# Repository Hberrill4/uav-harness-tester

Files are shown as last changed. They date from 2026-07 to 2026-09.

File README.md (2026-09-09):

# UAV harness continuity tester

ESP32-based automated continuity tester for a 64-wire UAV wiring harness.
Detects open circuits, shorts, and wire mismatches, and reports the exact
wire location of each fault. 

A custom PCB: [PCB](Workflow/Project-files/WireHarnessTesterPCB.zip) , [PCB schematic](Workflow/Project-files/WireHarnessTesterSchematic.zip) , 

and custom Enclosures:
[Main tray](Workflow/Project-files/Final_Tray.stl) ,
[Main lid](Workflow/Project-files/Final_Lid.stl) , 
[Test pod tray](Workflow/Project-files/Box%20for%20test%20pod%20v2.stl) , 
[Test pod lid](Workflow/Project-files/lid%20new.stl)

was designed made for this project

## How it works

One button drives everything:

- **Short press** — runs a test (normal mode) or captures a golden
  reference sample (admin mode)
- **Hold 5 seconds** — toggles between normal and admin mode (LCD turns
  blue in admin mode)

Every test scans all 64 wires against all 64 sense channels (not just a
1:1 diagonal check), which is what makes shorts and mismatches detectable,
not just opens. Results show on the LCD (pass = green, fail = red,
admin = blue) and get logged with a timestamp to the SD card.

See [Workflow/fault-report-format.md](Workflow/fault-report-format.md) for what a
fault report looks like and how faults are classified.

See [Workflow/User Manual](Workflow/User%20Manual) for full manual

## Table of contents

### src/
- **[Config](src/Config.h)** — All pin assignments, timing constants, wire count. File to edit hardware changes.
- **[main.cpp](src/main.cpp)** — Owns the state machine (normal/admin, test/capture)
- **[ButtonManager.](src/ButtonManager.h)** — Non-blocking debounce + short-press vs 5s-hold detection
- **[MuxController](src/MuxController.h)** — Addresses any of the 64 wires across the drive/sense mux banks
- **[ContinuityTester](src/ContinuityTester.h)** — Runs the full 64×64 connectivity scan
- **[FaultAnalyzer](src/FaultAnalyzer.h)** — Classifies faults: OPEN / SHORT / MISMATCH, with location
- **[WireMap](src/WireMap.h)** — Converts wire index → connector+pin label (e.g. "J1-13")
- **[DisplayManager](src/DisplayManager.h)** — LCD + RGB
- **[StorageManager](src/StorageManager.h)** — SD card logging + golden sample persistence

### Workflow/
- **[wiring-reference.md](Workflow/wiring-reference.md)** — Hardware assumptions baked into the code, pin mapping conventions
- **[fault-report-format.md](Workflow/fault-report-format.md)** — What fault reports look like and how they're generated
- **[Assembly](Workflow/Assembly/)** — The process behind the prototype and how everything was made
- **[Design-Architecture](Workflow/Design-Architecture/)** — General system layout and how components interact and connect
- **[Design-Enclosure](Workflow/Design-Enclosure/)** — Modular test pod and enclosure for bench-top testing
- **[Design-PCB](Workflow/Design-PCB/)** — PCB design process and final product
- **[Hardware](Workflow/Hardware/)** — Components considered and finalized design decisions
- **[Images](Workflow/Images/)** — Contains all images used throughout the documentation
- **[Project-files](Workflow/Project-files/)** — Contains all external project files
- **[User Manual](Workflow/User%20Manual/)** — Full user manual covering operation, maintenance, and troubleshooting
    
**platformio.ini**            Build config (ESP32, Arduino framework)

## Project Files

- [Bill of Materials](/Workflow/Project-files/BOM%20for%20project.csv)
- [Gant Chart](/Workflow/Project-files/Gant%20Chart.xlsx)
- [Test pod BOM](/Workflow/Project-files/Test%20pod%20BOM.pptx)
- [Adaptor BOM](/Workflow/Project-files/Adaptor%20BOM.pptx)

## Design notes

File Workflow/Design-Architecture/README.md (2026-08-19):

# Design Architecture

## Requirements

- Minimum 50 wires
- Stand-alone device
- Modular test pods (adaptor for multiple wire connectors)
- Display screen (shows pass/fail and fail type)
- Memory storage for matrices and results (golden sample)
- Display location and type of fail
- Sturdy, universal wire connection resistant to in/out movement, easy to click in

## Design Evolution

**Initial idea:** Store multiple harness types on an SD card, load the relevant one into RAM, and compare it against the connected harness, navigated via a scroll-wheel menu (new harness / test / view results). Rejected — only one "golden sample" is needed at a time, and this added test time and complexity without being user friendly. It would also create admin problems and using the scroll wheel may cause issues.

**Input method thinking:** The goal was a single button for most users, with a touch-screen password for admins to change the golden sample. Since a separate touch-input screen would undermine the simplicity goal, the team settled on using the same button for everything. This touch screen would then be two seperate screen which woukd overcomplicate the process and cause the test box to be too bulky.

## Final Design

A single button provides all input.

- **Normal use:** connect harness → press button → test runs → result + timestamp logged to SD → result shown on screen.
- **Admin mode:** hold the button 5 seconds to enter admin mode (shown via icon/text color change); connecting the golden sample and pressing the button stores it as the new reference. Hold 5 seconds again to exit.
- **Status colors:** Pass = green, Fail = red, Admin = blue.

This keeps the interface simple for everyday users while keeping the golden-sample update path deliberately non-obvious, and all results (with timestamps) are recoverable by plugging the SD card into a PC.
## Harness/cable considerations
A DSub mount connected to a ribbon cable which can connect to the Dsub connector on the outside of the box would keep everything contained and have a fixed position to conect to on the outisde of the box. Using Dsub wire connectors for our floating umbilical cords should also keep the connection stable and be resistant to general use. DIN connectors were also considered but problems with sturdiness and reliability of connection arose aswell as number of pins as the tester is designed to accomadate for a 64 wire loom.

## Component Architecture
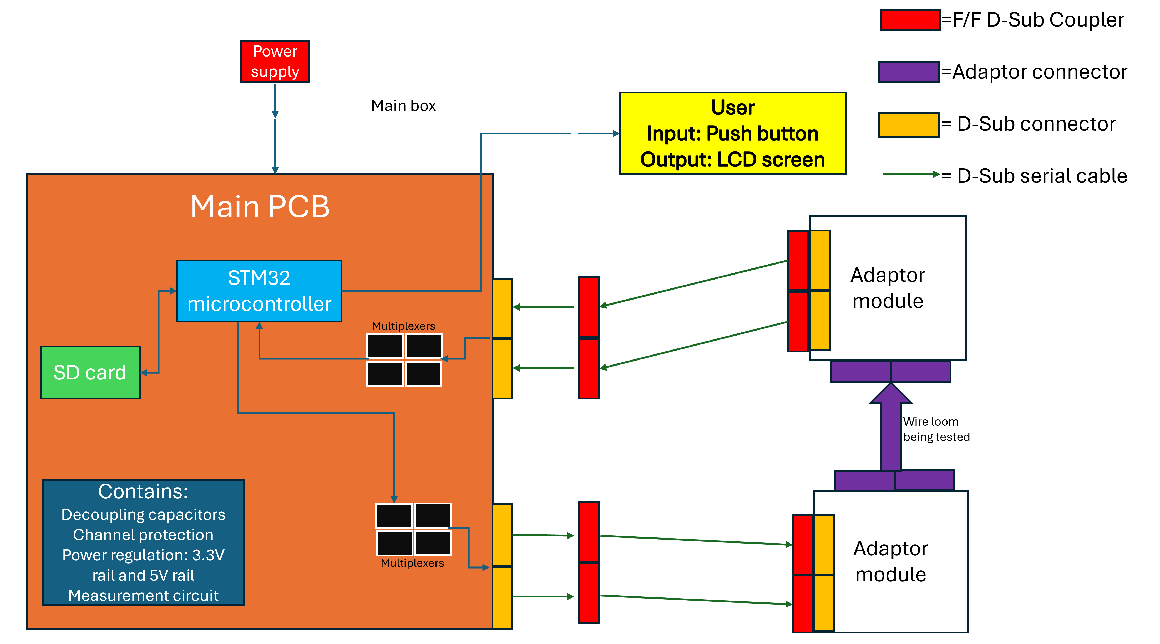
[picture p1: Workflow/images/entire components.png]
Component architecture diagram

The main box houses the Main PCB (ESP32-S3 microcontroller, multiplexers, SD card, decoupling capacitors, channel protection, and power regulation providing a 3.3V rail) plus the push-button input and LCD output. Two adaptor modules connect through D-Sub couplers and cabling to the wire loom under test.

## Operating Process
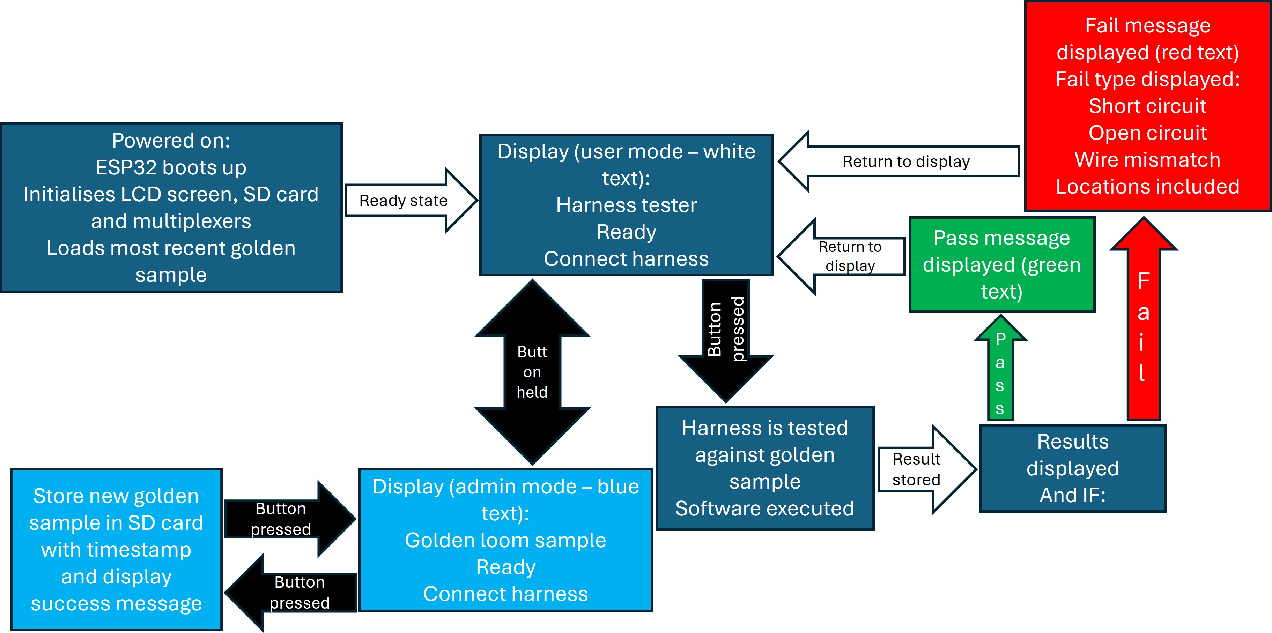
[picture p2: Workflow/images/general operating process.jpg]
General operating process diagram

On power-up, the ESP32 boots, initializes the LCD, SD card, and multiplexers, then loads the most recent golden sample. In user mode the display reads "Harness tester — Ready — Connect harness." Pressing the button runs the test against the golden sample; a pass shows a green message, a fail shows red with the fail type (short circuit, open circuit, or wire mismatch) and location. Holding the button switches to admin mode (blue text, "Golden loom sample — Ready — Connect harness"), where pressing the button stores a new golden sample to the SD card with a timestamp.

## Block Diagram
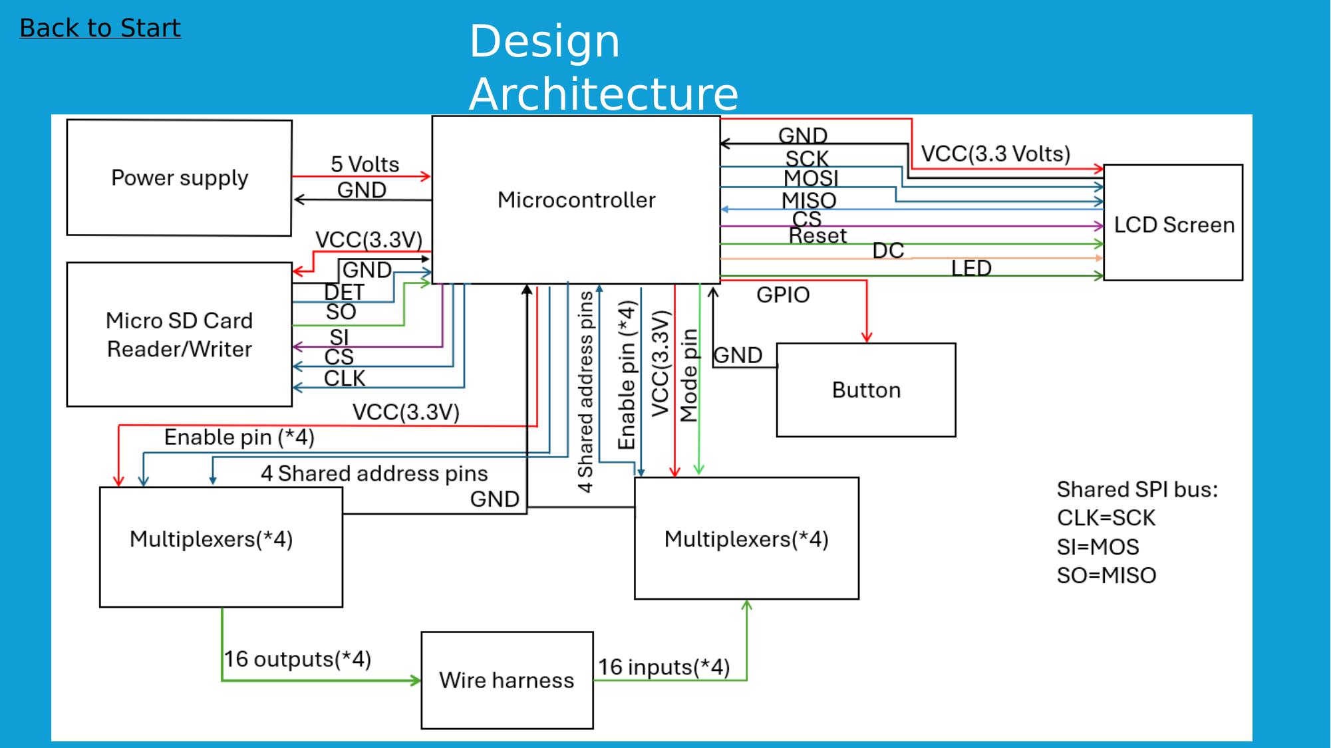
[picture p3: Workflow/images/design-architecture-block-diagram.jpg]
Block diagram

Shows the electrical connections between the power supply, microcontroller, LCD screen, microSD card reader/writer, button, and two sets of multiplexers, including the shared SPI bus (CLK/SI/SO mapped to SCK/MOSI/MISO) and the 16-input/16-output connections to the wire harness under test.

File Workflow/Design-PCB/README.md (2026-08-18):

# PCB Design

This document covers the custom PCB design using the software KiCAD for the UAV wire harness continuity tester: an ESP32-S3-based instrument that tests all 64 wires of a UAV harness for continuity and fault conditions, logs results with timestamps, and displays outcomes on an onboard TFT via a single-button interface.

See the [main README](../../README.md) for the full project overview and [`Workflow/Hardware`](../Hardware/) for the core hardware review that shaped these decisions and [Test pod Bill of Materials](https://github.com/Hberrill4/uav-harness-tester/blob/main/Workflow/Project-files/Test%20pod%20BOM.pptx) for the full list of test pod hardware used and [Adaptor pod Bill of Materials](https://github.com/Hberrill4/uav-harness-tester/blob/main/Workflow/Project-files/Adaptor%20BOM.pptx) for full list of adaptor hardware. Each PCB contains components of their respective BOM.

Final Test Pod Schematic: [Active PCB Schematic](https://github.com/Hberrill4/uav-harness-tester/blob/main/Workflow/Project-files/Active%20PCB%20Schematic.zip)

Final Test Pod PCB:

---

## Architecture at a glance

- ESP32-S3 drives 8× CD74HC4067 16-channel multiplexers (4 "drive" / 4
  "sense") to scan a full 64×64 wire matrix
- Results are logged to microSD and shown on a 2.8" TFT
- A single push button handles all user input, including an
  administrator mode
- The harness under test connects via modular pods over a floating
  umbilical interconnect

## Functional requirements

**Test coverage**
- Test all harness wires (up to 64) for continuity and fault conditions
- Store a golden sample reference in RAM and persist it to SD card

**Data & UI**
- Log every test result with a timestamp
- Display results on the 2.8" TFT
- Operate entirely from a single push button, including an administrator mode

**Interconnect**
- Interface with modular test pods over a floating umbilical
- Internal PCB-to-connector runs use IDC ribbon cable; the external
  umbilical uses a high-density D-sub or keyed circular connector with
  28–30 AWG stranded conductors, chosen for flex durability over repeated
  connect/disconnect cycles

**Electrical**
- USB-C input, 3.3V logic, SPI for TFT/SD, multiplexer channel switching
- Protection on all ESP32-facing measurement inputs

**A breadboard prototype was built and validated first** — see
[`../Assembly/`](../Assembly/) for the bring-up log — before committing
to PCB layout.

## Schematics
KiCAD was used to route all traces. Although a decision was made to mount the hardware components ourselves it was key to ensure the right components were selected in KiCAD to maintain the same dimensions and pin outs. Additional software like espressif was downloaded to ensure such accuracy could be maintained.

## Circuit protection

#### TVS Diode (4 Channel) — ESDR0524SMUTAG
The primary ESD/transient protection device on the board. Each package contains 4 low-capacitance channels, clamping voltage spikes on signal lines to a safe level whenever the external wiring harness is connected or disconnected — the most likely source of electrostatic discharge into the sense/mux lines. The low-capacitance rating matters here because it protects the matrix scan lines without materially loading them or slowing signal edges.

#### 10 µF Electrolytic Capacitor — MCESL16V106M4X5.2
Bulk reservoir capacitance. It provides a low-impedance path to absorb and dump the energy from any transient a TVS diode clamps, and smooths lower-frequency ripple on the rail — complementing the fast, small-value ceramics rather than replacing them. The 16V rating gives comfortable headroom above the logic/supply rail it's protecting.

#### 10 kΩ Resistor — RT0805FRE0710KL
Used as a pull-up resistor on the protected lines holding them at logic level 1 when nothing is actively driving them (e.g. before a harness is connected). This prevents floating inputs from producing false continuity/fault readings, working alongside the TVS clamping.

#### 0.1 µF Decoupling Capacitor — GCM155R71H104KE02J
Local high-frequency decoupling, placed as close as possible to IC power pins. It filters fast switching noise and supplies instantaneous current during transients, keeping the supply rail stable — standard practice paired with the bulk electrolytic above.

## Design workflow

-  Draft schematic — measurement circuit, power flags, net labels, test points, decoupling
-  Run ERC and resolve until clean
-  Assign footprints and verify against datasheets
-  Get schematic reviewed and approved
-  Import schematic into PCB editor
-  Arrange components — wide power traces, digital/analog separation
-  Route traces
-  Add ground plane
-  Run DRC
-  Inspect in 3D
-  Final review against schematic

**A breadboard prototype was built and validated first** — see
[`../Assembly/`](../Assembly/) for the bring-up log — before committing
to PCB layout.

## Known issues carried from design review

- Two GPIO pin conflicts (SD chip-select vs. mux enable; SPI clock/data
  vs. the Octal PSRAM bus) were identified and resolved during firmware
  bring-up — see commit history in `firmware/Config.h`
- Protection/measurement circuit block was absent from the original
  schematic and is being added in this revision
- Mux bank labeling was ambiguous when both banks looked identical on the
  original diagram; corrected with distinct drive/sense labeling

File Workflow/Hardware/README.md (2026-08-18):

## Microcontrollers Considered

**ESP32** — 45 changeable GPIO, 4 SPI, 3 UART, 2 I2C, 240 MHz clock, 8 MB flash, 512 KB SRAM, 384 KB ROM, 3.3 V logic. ([ESP32-S3-DEV-KIT-N8R8 overview](https://www.waveshare.com))

**Arduino Mega** — 16 analog inputs, 54 digital I/O (15 PWM), 4 serial ports, 16 MHz clock, 256 KB flash (8 KB used by bootloader), 8 KB SRAM, 4 KB EEPROM, 3.3 V logic.

The ESP32 is faster with more RAM/flash (good for future/industrial expansion) but its 3.3 V logic complicates inclusion. The Arduino Mega tests matrices one at a time — slightly slower, but makes good use of the SD card.

Finally the ESP32 was preferred as it provided more internal RAM which would allow the 64x64 matrices to be accessed in this way and improve the speed of the system massively as well as ease of use.

## Research: Existing Testers

| Tester | Source | Notes |
|---|---|---|
| Tester 1 | [theseus.fi thesis](https://www.theseus.fi/bitstream/handle/10024/801631/Ech-charef_Rania.pdf) | Discusses how to measure resistance during the process |
| Tester 2 | [hackaday.io – ArduWire Uno](https://hackaday.io/project/176753-arduwire-uno-low-voltage-cable-tester) | Uses a MUX/DEMUX 4067 IC to select pins, plus LEDs for a visual pass/fail indication; schematics provided, built around an Arduino Uno |
| Tester 3 | [Griffith University repository](https://research-repository.griffith.edu.au/server/api/core/bitstreams/e0df58bc-e96a-434f-b30a-f2ac24138317/content) | Covers wire harness testing methodology with a flow chart of the testing process |

## Other Component Considerations
- Was tough to find connecting cables that accommodated for a 64 wire harness so a decision was made to split it in half and use 2 idc rainbow ribbon cables inside of the modular test pod as they are already protected in that way and to use 2 DSsub connectors as the floating umbilical cords as these can withstand the daily usage and strain.  
- I also looked at the screen and lcd screen being able to share SPI bus ports as this would then require less GPIO pins on the Arduino.  
- Another consideration was monitoring the noise and surges that would happen due to there being many MUX switches so ceramic capacitors would be needed to mitigate this.  
- The MUX would have to have 4 control pins and 16 input/output pins while being able to operate on the esp32 to allow for switching between 64 wires.  
- A rotary encoder was originally looked at to be able to scroll through options but a single push button was decided upon as this would be far more user friendly and be able to easily be mounted on the modular test pod and only require one user input.  
- Headers would also be required to connect to the DSub cables off the PCB.

## Final Core Hardware

**Microcontroller:** ESP32-S3-DEV-KIT-NXRX - 45 changeable GPIO, 4 SPI, 3 UART, 2 I2C, 240 MHz clock, 8 MB flash, 512 KB SRAM, 384 KB ROM, 3.3 V logic.

**Display:** 2.8" ILI9341 SPI TFT — 169 KB internal display RAM, 3.3 V logic, 6 GPIO pins.

**Storage:** MicroSD SPI/SDIO breakout board — shares the SPI bus, needing only one extra pin.

**Multiplexer/Demultiplexer:** CD74HC4067 — 2–6 V operation, 16 channels, 4 control pins, enable pin

**DSub connector:** 37 Pin Dsub to Dsub males

**Test pod connectors:** High Speed Data Transfer Cord DB37 Data Cable Wire D-Sub 37Pin

**Total Bom for test pod is provided below:**  
[Bill of Materials](https://github.com/Hberrill4/uav-harness-tester/blob/main/Workflow/Project-files/Test%20pod%20BOM.pptx)

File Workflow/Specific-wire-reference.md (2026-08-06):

| Connection Type | Colour | Wire Reference |
|---|---|---|
| 🔌**S1** |  |  |
| <small>PPM</small> | <small>White</small> | **J1-1** |
| <small>N/A</small> | <small></small> |  |
| <small>GND</small> | <small>Black</small> | **J1-2** |
| 🔌**S2** |  |  |
| <small>PPM</small> | <small>White</small> | **J1-3** |
| <small>N/A</small> | <small>N/A</small> |  |
| <small>N/A</small> | <small>N/A</small> |  |
| 🔌**S3** |  |  |
| <small>PPM</small> | <small>White</small> | **J1-4** |
| <small>VCC</small> | <small>Red</small> | **J1-5** |
| <small>GND</small> | <small>Black</small> | **J1-6** |
| 🔌**S4** |  |  |
| <small>PPM</small> | <small>White</small> | **J1-7** |
| <small>VCC</small> | <small>Red</small> | **J1-8** |
| <small>GND</small> | <small>Black</small> | **J1-9** |
| 🔌**S5** |  |  |
| <small>PPM</small> | <small>White</small> | **J1-10** |
| <small>VCC</small> | <small>Red</small> | **J1-11** |
| <small>GND</small> | <small>Black</small> | **J1-12** |
| 🔌**S6** |  |  |
| <small>PPM</small> | <small>White</small> | **J1-13** |
| <small>VCC</small> | <small>Red</small> | **J1-14** |
| <small>GND</small> | <small>Black</small> | **J1-15** |
| 📡**Receiver** |  |  |
| <small>4V5</small> | <small>Red</small> | **J1-16** |
| <small>T4</small> | <small>White</small> | **J1-17** |
| <small>R4</small> | <small>Yellow</small> | **J1-18** |
| <small>T2</small> | <small>Blue</small> | **J1-19** |
| <small>R2</small> | <small>Green</small> | **J1-20** |
| <small>GND</small> | <small>Black</small> | **J1-21** |
| 🖥️**Carrier J16** |  |  |
| <small>USB-</small> | <small>Black</small> | **J1-22** |
| <small>USB+</small> | <small>White</small> | **J1-23** |
| <small>USB GND</small> | <small>Shield</small> | **J1-24** |
| 📶**VTX** |  |  |
| <small>9V</small> | <small>Red</small> | **J1-25** |
| <small>GND</small> | <small>Black</small> | **J1-26** |
| <small>TX5</small> | <small>Blue</small> | **J1-27** |
| <small>VTX</small> | <small>Yellow</small> | **J1-28** |
| ⚡**PDB** |  |  |
| <small>VBATT</small> | <small>Red</small> | **J1-29** |
| <small>GND</small> | <small>Black</small> | **J1-30** |

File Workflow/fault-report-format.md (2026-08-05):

# Fault report format

## Types

| Type | Meaning | Example |
|---|---|---|
| `OPEN` | No continuity anywhere on this wire | `OPEN:J1-12` — pin 12 on connector J1 is broken/disconnected |
| `SHORT` | Wire reaches its correct pin, but also touches another pin it shouldn't | `SHORT:J1-5-J2-9` — J1 pin 5 and J2 pin 9 are shorted together |
| `MISMATCH` | Wire reaches a pin, but not the one it's supposed to | `MISWIRE:J1-20-J2-1` — the wire meant for J1 pin 20 landed on J2 pin 1 instead |

## Where faults show up

- **LCD (live)**: first 8 faults with type + location, plus a "+N more, see
  log" line if there are more than that. This keeps each fault readable at
  a glance on the 2.8" TFT without needing to scroll; the full list is
  always available in the SD log regardless of what's shown live.
- **SD card log** (`test_log.csv`): every fault from every test, one row
  per test run:

  ```
  timestamp,test number,result,faults
  1737654321,23,FAIL,OPEN:J1-12;SHORT:J1-5-J2-9;MISWIRE:J1-20-J2-1
  1737654890,PASS,
  ```

## How faults are determined

Every test compares the live 64x64 connectivity scan against an "expected"
matrix:

- If a **golden sample** has been captured (admin mode), that becomes the
  expected matrix and is the change is logged on the SD.
- Otherwise, the firmware assumes a straight-through harness (wire N should
  only ever reach pin N) — see `ContinuityTester::identityExpectation()`.

Capturing a golden sample is recommended for any harness that isn't a
simple 1:1 pass-through, since the identity assumption will otherwise flag
correct-but-nonstandard wiring as mismatches.

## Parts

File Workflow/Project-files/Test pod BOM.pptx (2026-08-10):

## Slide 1

Description | Part Number | Quantity | Supplier URL | ID | Image | Cost (£)
32 Bit Microcontroller | ESP32-S3-DEVKITC-1U-N8R8 | 1 | https://www.amazon.co.uk/Waveshare-Development-ESP32-S3-WROOM-1-Processor-Connector/dp/B0DLWGVXCS | ESP32-S3-DEV-KIT-16MB | | 15.35
2.8 LCD Display Module With MicroSD Socket | 1770 | 1 | https://uk.rs-online.com/web/p/display-development-tools/1245469 | ILI9341 | | 23.13
16:1 multiplexer | CD74HC4067M96 | 8 | https://uk.rs-online.com/web/p/multiplexer-demultiplexer-ics/6622577 | CD74HC4067M96 | | 4.21
Micro SD card | SP008GBSTH010V10SP | 1 | https://uk.rs-online.com/web/p/sd-cards/2883799 | 8 GB MicroSDHC microSD, Class 10 | | 9.24
F/F 37-way D-Sub coupler | 09670374701 | 4 | https://uk.rs-online.com/web/p/d-sub-connectors/1007822 | HARTING D-Sub 37 Way Straight Cable D-Sub Connector | | 8.44
0.1uF Decoupling capacitor | GCM155R71H104KE02J | 10 | https://www.digikey.co.uk/en/products/detail/murata-electronics/GCM155R71H104KE02J/4903705 | 0.1 µF ±10% 50V Ceramic Capacitor X7R 0402 | | 0.26
Snap-in arcade button | OBSF-30RG | 1 | https://thepihut.com/products/official-sanwa-arcade-button-long-life | Sanwa Round 30mm Long Life Snap-in Arcade Button | | 4.90
10uF Electrolytic capacitor | MCESL16V106M4X5.2 | 9 | https://uk.farnell.com/multicomp-pro/mcesl16v106m4x5-2/cap-10-f-16v-radial-smd/dp/9265686 | SMD Aluminium Electrolytic Capacitor, Radial Can - SMD, 10 µF | | 1.68
10k Resistor | RT0805FRE0710KL | 8 | https://uk.rs-online.com/web/p/surface-mount-resistors/1985686 | Yageo RT 10 kΩ, 0805 Thin Film Surface Mount Resistor | | 0.24
TVS Diode | ESDR0524SMUTAG | 32 | https://www.mouser.co.uk/en/ProductDetail/onsemi/ESDR0524SMUTAG | ESD Protection Diodes / TVS Diodes 4 CHAN LOW CAP ESD PROT | | 10.66
37 pin Female D-Sub mount connector | 5504F1-37S-02-03-F1 | 4 | https://cpc.farnell.com/multicomp-pro/5504f1-37s-02-03-f1/socket-d-pcb-r-a-37-way/dp/CN11147 | 37 Pin D-Sub Right Angle PCB Socket with Boardlock | | 3.20
M/M 37 wire D-Sub cable | 9482490105136 | 4 | https://www.fruugo.co.uk/high-speed-data-transfer-cord-db37-data-cable-wire-d-sub-37pin-connectors-line/p-352918890-768284818 | DB37 Crimped Ribbon Data Cable | | 23.80

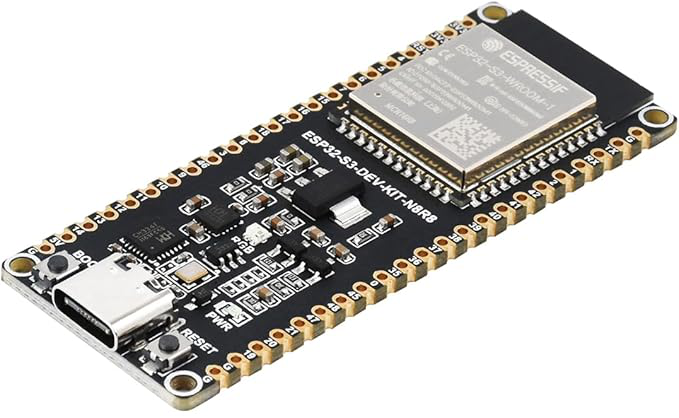
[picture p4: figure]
Waveshare ESP32-S3 Wi-Fi Development Board with ESP32-S3-WROOM-1 Series Module, 240MHz Dual Core Processor, 512KB SRAM, 8MB PSRAM, 16MB Flash, Type-C Connector
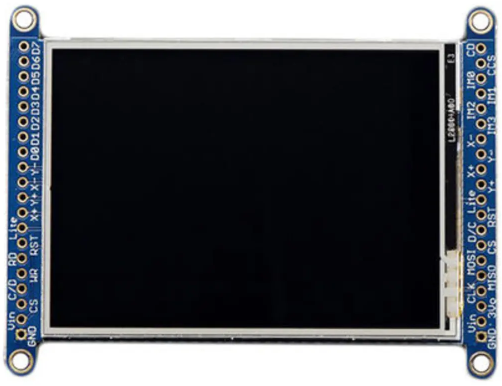
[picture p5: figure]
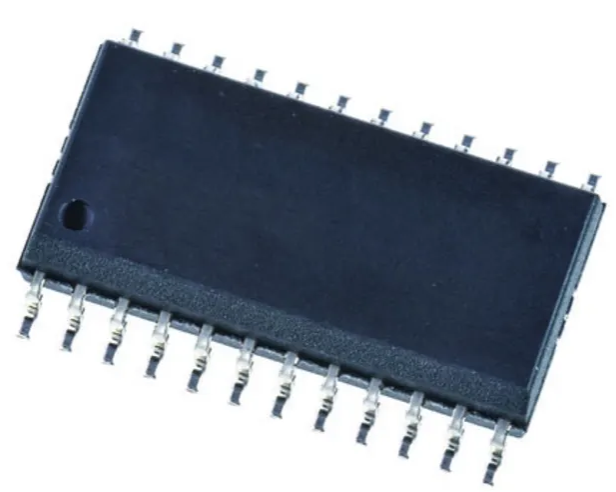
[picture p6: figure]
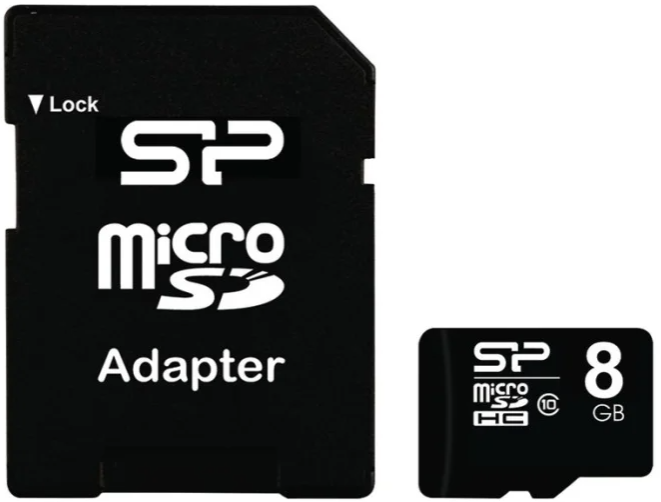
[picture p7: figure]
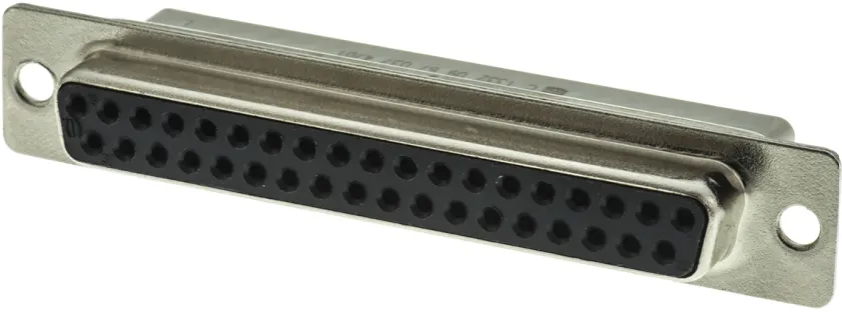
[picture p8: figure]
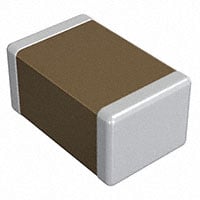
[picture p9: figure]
0.1 µF ±10% 50V Ceramic Capacitor X7R 0402 (1005 Metric)
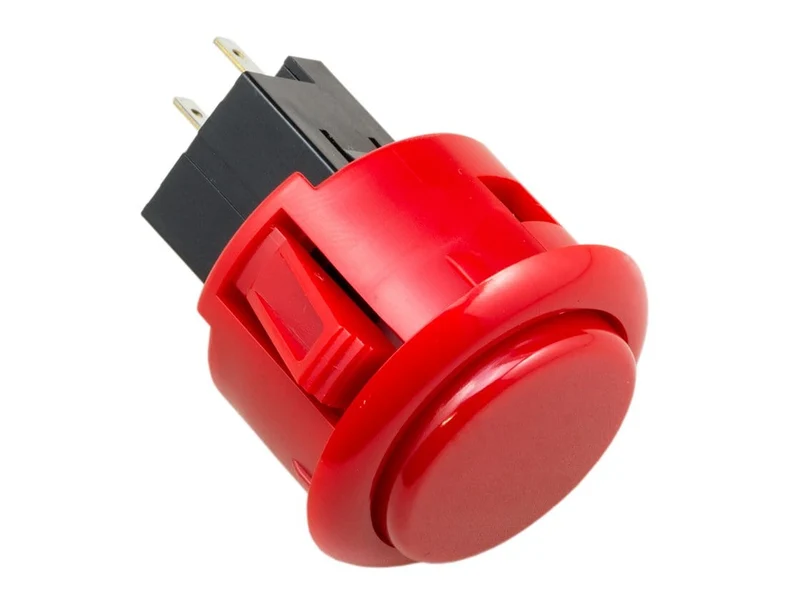
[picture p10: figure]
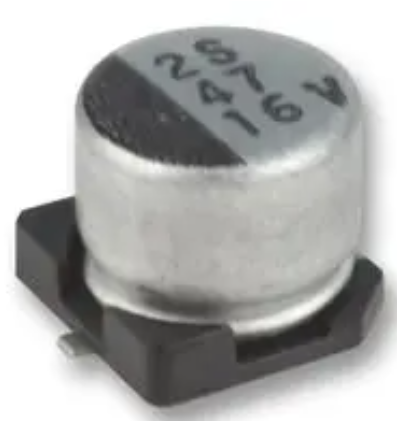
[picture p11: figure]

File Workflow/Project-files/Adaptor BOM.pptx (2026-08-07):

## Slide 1

Description | Part Number | Quantity | Supplier URL | ID | Image | Cost (£)
M/M D-Sub Cable | RND 765-00044 | 4 | https://uk.rs-online.com/web/p/serial-cables/2834340 | RND Male D-Sub 37-Pin to Male D-Sub 37-Pin Serial Cable, 1 m, RND Series | | 34.64
XT30 Male connector | | 1 | https://www.hobbyrc.co.uk/xt30-male-connectors-2x-male | XT30 Male Connectors (2x Male) | | Already have
JST GH 6 Way Male | SM06B-GHS-TB(LF)(SN) | 1 | https://uk.rs-online.com/web/p/pcb-headers/7521800 | JST GH Series Right Angle Surface PCB Header, 6 Contact(s), 1.25 mm Pitch | | 2.39
3 way Male pin header | 251-8092 | 6 | https://uk.rs-online.com/web/p/pcb-headers/2518092 | RS PRO Straight Through Hole Pin Header, 3 Contact(s), 2.54 mm Pitch | | Already have
37 pin Female D-Sub mount connector | 5504F1-37S-02-03-F1 | 4 | https://cpc.farnell.com/multicomp-pro/5504f1-37s-02-03-f1/socket-d-pcb-r-a-37-way/dp/CN11147 | 37 Pin D-Sub Right Angle PCB Socket with Boardlock | | 3.20
Servo Connector | | 6 | | | | Already have
JST GH 4 Way Male | SM04B-GHS-TB(LF)(SN) | 1 | https://uk.rs-online.com/web/p/pcb-headers/7521797 | JST GH Series Right Angle Surface PCB Header, 4 Contact(s), 1.25 mm Pitch | | 1.87
JST SH 4 Way Mount | SM04B-SRSS-TB(LF)(SN) | 1 | https://cpc.farnell.com/jst-japan-solderless-terminals/sm04b-srss-tb-lf-sn/connector-header-smt-r-a-1mm-4way/dp/CN26550 | Pin Header, Right Angle, Wire-to-Board, 1 mm, 1 Rows, 4 Contacts, Surface Mount Right Angle | | 0.26
15 pin female D-Sub mount | 5504F1-15S-02-03-F1 | 1 | https://cpc.farnell.com/multicomp-pro/5504f1-15s-02-03-f1/socket-d-pcb-r-a-15-way/dp/CN11145 | 15 Pin D-Sub Right Angle PCB Socket with Boardlock | | 0.52
M/F 15 pin D-Sub cable | | 2 | https://www.amazon.co.uk/JSADZKJ-Extension-Connecter-Straight-Computers/dp/B0D95BSP16/ref=sr_1_1_sspa | Serial (15-Pin) DB15 RS 232 Converter Cable | | 11.99
Custom made JST GH 4 and 6 way & SH 4 way extension cables. | | 1 of each
15 pin male D-Sub mount | 8LCM015P-301B-XX | 1 | https://cpc.farnell.com/multicomp-pro/8lcm015p-301b-xx/plug-d-pcb-r-a-15way/dp/CN15215 | 15 Pin D-Sub Right Angle PCB Plug | | 6.48


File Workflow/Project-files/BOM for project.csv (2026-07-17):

Name | Description | Qty | unit cost (No VAT)(£) | delivery | cost(£) | Product link | datasheet | .
ESP32-S3-DEV-KIT-NXRX | 32 bit Microcontroller | 1 | 15.35 | 0 | 15.35 | https://www.amazon.co.uk/Waveshare-Development-ESP32-S3-WROOM-1-Processor-Connector/dp/B0DLWGVXCS | https://docs.waveshare.com/ESP32-S3-DEV-KIT-N8R8 | .
Dsub coupler | F/F 37 pins | 8 | 2.11 |  | 16.88 | https://uk.rs-online.com/web/p/d-sub-connectors/1007822?matchtype=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 | https://docs.rs-online.com/b35c/A700000014553755.pdf | .
Male D-Sub 37-Pin to Male D-Sub 37-Pin Serial Cable | 37 Pin Dsub M/M | 4 | 8.66 |  | 34.64 | https://uk.rs-online.com/web/p/serial-cables/2834340 | https://docs.rs-online.com/03de/A700000010982135.pdf | .
D-Sub 37 Way Straight Cable D-Sub Connector | 37 Pin Dsub conector 5Pcs | 1 | 4.346 |  | 21.73 | https://uk.rs-online.com/web/p/d-sub-connectors/5443878 | https://docs.rs-online.com/f677/A700000007669984.pdf | .
Resistive Touch Screen Display Module | 2.8" LCD using SPI | 1 | 23.13 | 0 | 23.13 | https://uk.rs-online.com/web/p/display-development-tools/1245469 | https://docs.rs-online.com/4ddc/0900766b81534372.pdf | .
MicroSD Breakout | MicroSD Breakout | 1 | 3.3 |  | 3.3 | https://thepihut.com/products/microsd-breakout | https://github.com/adafruit/MicroSD-breakout-board | .
CD74HC4067ÿModule | 16 bit de/multiplexer 1Pcs | 8 | 2.99 | 0 | 23.92 | https://38-3d.co.uk/products/cd74hc4067-analogue-digital-multiplexer-module | https://www.ti.com/lit/ds/symlink/cd74hc4067.pdf | .
CD74HC4067M96 | 16 bit de/multiplexer 10Pcs | 1 | 4.21 |  | 4.21 | https://uk.rs-online.com/web/p/multiplexer-demultiplexer-ics/6622577 | https://www.ti.com/lit/ds/symlink/cd74hc4067.pdf | .
Micro SD card | Micro SD card 8GB | 3 | 9.24 | 0 | 27.72 | https://uk.rs-online.com/web/p/sd-cards/2883799 | https://docs.rs-online.com/0636/A700000011340737.pdf | .
Breadboards | 830 Points 3 Pcs | 2 | 8.04 |  | 16.08 | https://amazon.co.uk/dp/B01M0QJTI5 |  | .
Button | 30mm Red button from laszlo | 1 | 0 | 0 | 0 |  |  | .
Jumperwires | M/M | 3 | 1.7 |  | 5.1 | https://thepihut.com/products/premium-male-male-jumper-wires-20-x-6-150mm |  | .
USB C cable | USB C cable | 1 | 4.42 |  | 4.42 | https://cpc.farnell.com/pro-signal/psg91477/lead-usb30-a-male-usb-type-c-gen-1-1m/dp/CS30873 |  | .
USB Plug | USB Plug | 1 | 5.99 |  | 5.99 | https://amazon.co.uk/dp/B0BV65Y6B2 |  | .
Female pin headers | Female pin headers(50) | 1 | 5.3 |  | 5.3 | https://uk.rs-online.com/web/p/pcb-headers/2837928 | https://docs.rs-online.com/03ef/A700000011064526.pdf | .
High Speed Data Transfer Cord DB37 Data Cable Wire D-Sub 37Pin | M/M Dsub connector 0.2m | 4 | 5.95 |  | 23.8 | https://www.fruugo.co.uk/high-speed-data-transfer-cord-db37-data-cable-wire-d-sub-37pin-connectors-line/p-352918890-768284818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 | .
 |  |  |  |  | 231.57

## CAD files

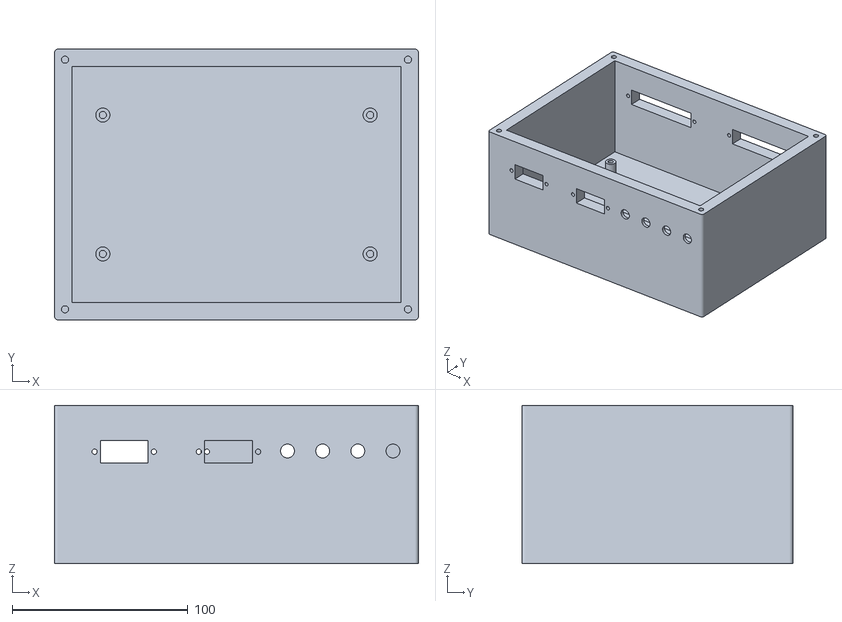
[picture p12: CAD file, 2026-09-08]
Workflow/Project-files/Box for test pod v2.stl
207.0 x 154.0 x 90.0

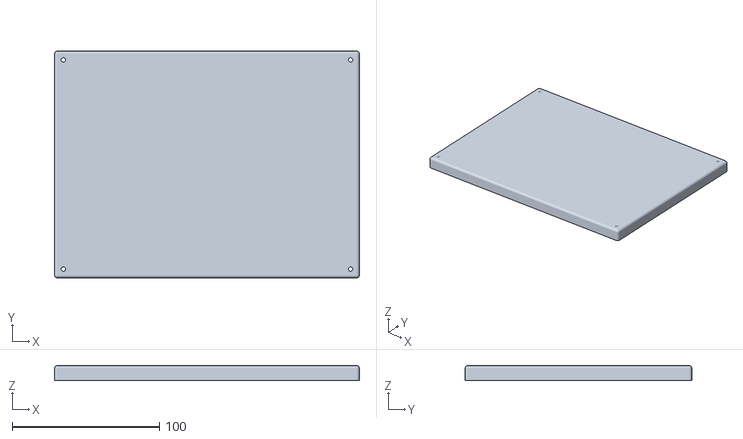
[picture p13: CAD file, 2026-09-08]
Workflow/Project-files/lid new.stl
207.0 x 154.0 x 10.0

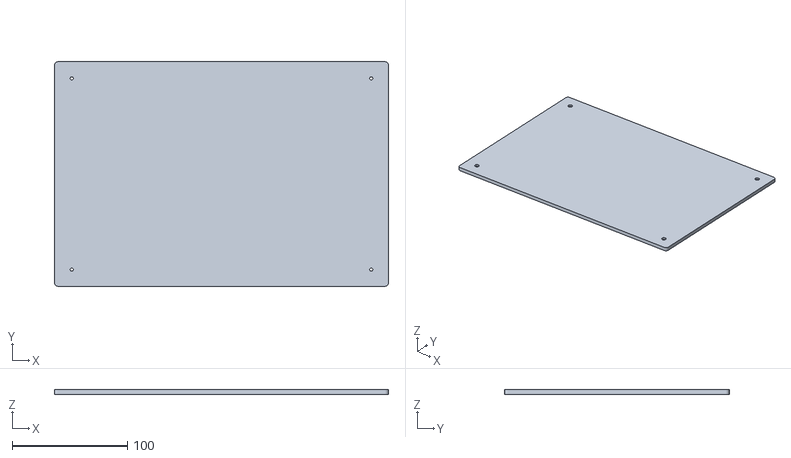
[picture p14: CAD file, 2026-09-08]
Workflow/Project-files/Final_Lid.stl
290.0 x 195.0 x 4.00

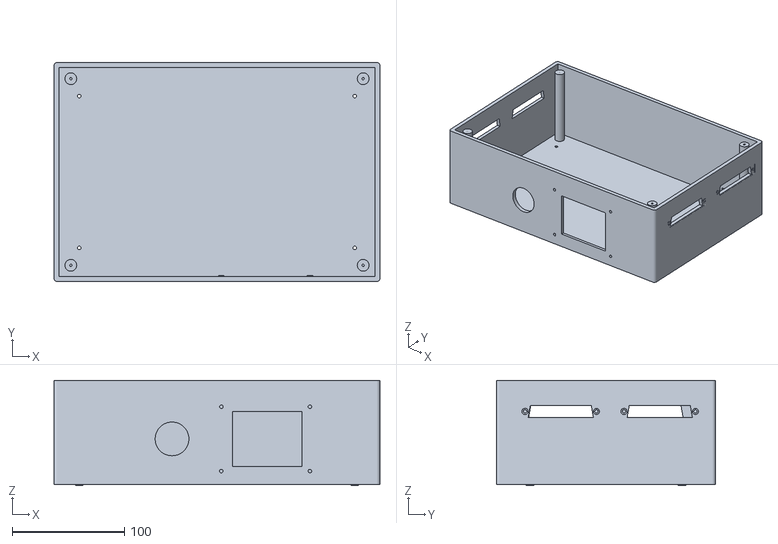
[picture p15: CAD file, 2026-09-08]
Workflow/Project-files/Final_Tray.stl
290.0 x 195.0 x 93.5

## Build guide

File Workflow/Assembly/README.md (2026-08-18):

# UAV Harness Tester — Prototype Build Guide
### (using the real `Config.h` — Waveshare ESP32-S3-DEV-KIT-N16R8)

## Phase 1 — Power and ground

- [ ] Build a common 3.3V rail and ground bus on the breadboard.
- [ ] Add decoupling capacitors near the LCD and near each mux IC (0.1 µF
  ceramic)
- [ ] Confirmed rail voltage under load with a multimeter before connecting
  any ICs

## Phase 2 — Display bring-up (ILI9341)

Wire, using the corrected pin map:

| Signal | GPIO |
|---|---|
| SCK  | 19 (corrected) |
| MOSI | 20 (corrected) |
| MISO | 47 (verify 3.3V first) |
| CS | 40 (`PIN_TFT_CS`) |
| DC | 41 (`PIN_TFT_DC`) |
| RST  | 42 (`PIN_TFT_RST`) |

- [ ] Wire the table above, plus backlight/LED to 3.3V
- [ ] Flash just `DisplayManager`'s init + a test screen.
- [ ] **Expect:** a stable, correctly-oriented test image with no tearing,
  no random pixels, no color inversion.
- [ ] Confirmed this works cleanly before moving on as SPI wiring issues are
  much easier to isolate now than once the SD card and muxes are also on
  the bus.

## Phase 3 — microSD bring-up

- [ ] Wire SD card SPI: shares SCK (19), MOSI (20), MISO (47) with the
  LCD, but has its own CS on **GPIO 39** (`PIN_SD_CS`).
- [ ] Flash `StorageManager` alone and confirm you can write and read back
  a log file at `/test_log.csv`.
- [ ] **Expect:** GPIO39 reads HIGH immediately after reset which is the correct
  idle state for an SPI CS line, so nothing to fix there.
- [ ] Test with the card inserted and removed to know what the
  failure mode looks like 

## Phase 4 — Button input

- [ ] Wire the single push-button to **GPIO 4** (`PIN_BUTTON`)
- [ ] Flash `ButtonManager` alone and confirm short-press, long-press
  (≥5000ms per `LONG_PRESS_MS`), and no false triggers from switch bounce

## Phase 5 — One mux pair (proof of concept)

Drive bank (first chip only):

| Signal | GPIO |
|---|---|
| S0 | 13 |
| S1 | 12 |
| S2 | 14 |
| S3 | 15 |
| SIG | 1 |
| EN[0] | 6 |

Sense bank (first chip only):

| Signal | GPIO |
|---|---|
| S0 | 16 |
| S1 | 17 |
| S2 | 5 |
| S3 | 18 |
| SIG | 48 |
| EN[0] | 21 |

- [ ] Wired just these two chips: shared S0-S3 address lines within each
  bank, separate EN lines.
- [ ] Flash Microcontroller
- [ ] Connect wires between MUXs and scan as golden sample
- [ ] Return to test screen to then test same wire and confirm it passes and is displayed:[Pass evidence](https://github.com/Hberrill4/uav-harness-tester/blob/main/Workflow/images/IMG_8664.MOV)
- [ ] Disconnect one wire and switch two wires around to confirm open and crossed wire fault detection:[Fail evidence](https://github.com/Hberrill4/uav-harness-tester/blob/main/Workflow/images/IMG_8665.MOV)

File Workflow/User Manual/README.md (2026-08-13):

# UAV harness tester — User Manual
### UAV Wire Harness Continuity Tester

**Document version:** v0.2 (draft)
**Date:** 2026-08-DD
**Author:** Harrison Berrill

## 1. Introduction

- **Purpose:** Verifies continuity across a wire harness against a known-good "golden sample" for up to 64 wires. flags OPEN/SHORT/MISMATCH faults and their location. Saves test number, result of scan and when a new golden harness is submitted onto an SD card. It replaces manual time consuming point-to-point ohmmeter checks
- **Intended audience:** Assembly technicians, Drone operators or anyone using a wire loom.
- **Scope:** This Manual covers usage, troubleshooting and maintenance. The development of the product and code/firmware are covered separately in the repo.
- **Key features:**
  - Full matrix scan across [N]×[N] wire matrix
  - Golden-sample capture and comparison
  - Color-coded display
  - Open, Mismatch and Closed wire fault location
  - On-device result logging to SD card

---

## 2. Safety Information

### 2.1 ⚡ Electrical Precautions

- **Test lead voltage/current limits:** This tester is a **passive continuity tester only** — it applies a low-voltage sense signal (3.3 V logic level from the ESP32-S3) through the mux network to detect open/short/mismatch conditions. It does not source test voltage/current beyond this. Do not connect the DC37 test leads to any harness, wire bundle, or circuit that carries its own voltage source.

- **TVS diode rating (`ESDR0524SMUTAG`):** Each mux input is protected by an `ESDR0524SMUTAG` dual/quad-element TVS array with a **5 V reverse standoff voltage** and a **5.5–6 V breakdown voltage**. Under ESD transient conditions the clamping voltage can reach up to **15 V max** — this is a *transient protection* spec, not a sustained-voltage rating.

  > ⚠️ **Treat 5 V as the absolute ceiling** for any voltage present on a wire under test. This protection exists for ESD events, not for testing energized circuits — see [2.3](#23--do-not-test-energizedlive-harnesses).

- **ESD handling — ESP32-S3 and mux ICs:** The ESP32-S3-WROOM-1 module and CD74HC4067 muxes are CMOS devices vulnerable to static discharge.
  - Use an anti-static wrist strap or mat when handling the bare PCB, especially before full assembly.
  - Store the assembled tester in an anti-static bag when not in use.
  - Handle by PCB edges or connector shells — avoid touching mux input pins or the WROOM module pins directly.

<small>TVS diodes: onsemi `ESDR0524SMUTAG`, U-DFN2510, 4-element common anode.</small>

---

### 2.2 🔌 Power Source Warnings

- **Power input:** The tester is powered exclusively via **USB** through the ESP32-S3-DevKitC. There is no battery in the design — no charging precautions apply.
- Use only a USB cable and power source rated for the ESP32-S3's requirements (5 V, standard USB current limits). Do not use damaged USB cables or connectors.
- Disconnect USB power before making or breaking connections at the DC37 connectors or any exposed header.

---

### 2.3 🚫 Do Not Test Energized/Live Harnesses

> **This applies, without exception.**

The tester is designed exclusively for continuity/open/short/mismatch testing on **de-energized, unpowered wire harnesses**. Before every test session, confirm:

- [ ] The harness under test is fully disconnected from any UAV battery, ESC, flight controller power rail, or other voltage source.
- [ ] No capacitors in the harness (e.g., on ESC inputs) retain residual charge — allow bleed-down time or discharge safely first.
- [ ] Never connect the DC37 umbilical to a harness still mounted in a powered-on airframe.

Testing a live harness will exceed the TVS diode's 5 V standoff rating and can damage the mux ICs, the ESP32-S3, or the harness itself.

---

### 2.4 🔗 Umbilical Cable & Connector Handling

- **Cable:** RND `765-00044`, male–male 37-pin D-Sub, 1 m. No manufacturer bend-radius spec is published for this cable — as a conservative general D-Sub cable practice, avoid bends tighter than **~8× cable OD**, and never bend sharply right at the connector backshell.
- **Temperature range:** The cable/connector assembly is rated **10 °C to 60 °C** per the manufacturer datasheet — this becomes the practical environmental ceiling/floor for the whole tester (see [2.5](#25--environmental-limits)), since it's the most restrictive component.
- **Strain relief:** Support the cable at the D-Sub shell, not at the pins. Anchor a strain-relief boot or cable tie to the enclosure rather than the connector shell itself.
- Mate/unmate D-Sub connectors straight-on — never at an angle — to avoid bending pins.
- Inspect D-Sub pins for bend or recession before each test session.

<small>Cable: RND 765-00044, 37-pin D-Sub M–M, 1 m, grey jacket, RoHS.</small>

---

### 2.5 🌡️ Environmental Limits

- **Operating temperature:** **10 °C to 60 °C**, set by the D-Sub umbilical cable rating (the limiting component — the TVS diodes are rated to −55 °C to +125 °C, well beyond this).

---

## 3. What's in the Box

- [ ] Tester unit
- [ ] Umbilical cable / connector to harness under test
- [ ] USB-C cable
- [ ] This guide

---

## 4. Product Overview

### 4.1 Physical Layout
- [ ] Insert labeled photo/diagram showing: display, buttons, status LED, connector(s), SD card slot, power switch/port
- Connector reference: J1 / J2 pinout — link to or summarize `docs/wiring-reference.md`

### 4.2 Controls
| User Type | Short Press | Long Press (5s hold) |
|---|---|---|
| Tester | Tests current wire harness | Switches to admin mode |
| Admin | Submits current harness as new golden sample | Switches to Tester mode |
| All | After scan its used to move off the test screen |

### 4.3 Indicators
| Indicator | State | Meaning |
|---|---|---|
| RGB LED | Green | Pass |
| RGB LED | Red | Fail |
| RGB LED | Blue | Golden sample mode |
| Display | — | Shows live scan status and fault report, color-coded per mode (see 4.4) |

*Note: GPIO48 (RGB LED) is shared with the onboard LED — cosmetic flicker during scans is expected, not a fault.*

### 4.4 Display Color Reference

| Mode / Result | Display Color | What it means |
|---|---|---|
| Idle / standby | white text | Waiting for a scan to start |
| Golden Sample Capture — menu | Cyan | Matrix scan ready to be submitted |
| Golden Sample Capture — success | Blue | Sample stored; wire count shown |
| Golden Sample Capture — failure | Red | 0 (or too few) wires detected — reseat harness and retry |
| Test Scan — No reference | Magenta | No golden sample to refer off |
| Test Result — PASS | Green | Scan matches golden sample exactly |
| Test Result — OPEN | Red | Expected connection missing |
| Test Result — SHORT | Red | Unexpected connection detected |
| Test Result — MISMATCH | Red | Connection present but on the wrong pin/wire |

The Display will also show the location of the failure and its type. eg. Mismatch J11->J13

---

## 5. Getting Started

### 5.1 Powering On
1. Connect USB-C to port
2. Components will initialize and appear ready to scan

### 5.2 Connecting a Harness
1. Connect the harness that's being tested to the 2 adaptors which connect via D-Sub to the main test enclosure
2. Ensure connection is fully secure

## 6. Operating Instructions

### 6.1 Capturing a Golden Sample
1. Connect a **known-good, verified** harness to J1/J2.
2. Hold button for 5 seconds to enter Golden Sample Capture mode (Admin mode).
3. The display turns **cyan** prompts to press the button again to conduct the scan.
4. On success, the display turns **blue** and prompts to press the button again to return to admin screen.
5. The sample is written to the SD card as the reference for all future scans and this new scan change is logged as such. A new golden sample being submitted overwrites the previous one.
6. To exit the admin screen, follow the on screen instruction to hold button for 5 seconds.

### 6.2 Running a Continuity Test
1. Connect the harness under test to J1/J2.
2. In tester mode Short-press button to start a scan.
4. Results populate the 20-column grid, one line per fault — or a single **"PASS"** line in green if the harness matches the golden sample exactly.
5. See 4.4 for the full color reference and 6.3 for what each result code means.

### 6.3 Interpreting Results
| Result Code | Color | Meaning | Typical Cause |
|---|---|---|---|
| OPEN | red | Expected connection not detected | Broken wire, bad crimp, unseated pin |
| SHORT | red | Unexpected connection detected | Pinched insulation, solder bridge |
| MISMATCH | red | Connection present but wrong pin/wire | Miswire, wrong harness variant |
| PASS | green | Matches golden sample | — |

See [Workflow/Specific-wire-reference.md](main/Workflow/Specific-wire-reference.md) for interpretation of results displayed for this harness. This table will also be on the particular adaptor pod.
Both a Fail and a Pass will be logged along with its test number. In the event of a fail all information about the fail will be logged like the type and location.

### 6.4 Saving / Exporting Results
- When the SD card if full, damaged or fails to log an error message will appear until the error is corrected or esp32 is reset.
- To retrieve logged data, remove the on board SD card from the ESP32 and plug it into a computer.

---

## 7. Menu & Display Navigation

General operating process diagram

---

## 8. Maintenance & Storage

- Cleaning: Dry compressed air or a soft brush on the SD card slot and exposed connector pins (mux inputs, umbilical connector); isopropyl alcohol on a lint-free cloth for the ILI9341 display, avoid pressure on the glass.
- Storage conditions: Cool, dry, away from direct sun (ILI9341 contrast can degrade above ~60°C); keep the umbilical connector capped when detached to protect the conductors from oxidation/damage.
- Power: USB-C powered only, no onboard battery. No charge-cycle or storage-charge considerations — just avoid leaving the USB-C port exposed to dust/moisture when not connected.
- Firmware update procedure: Connect the ESP32-S3 via USB-C, pull the latest from github.com/Hberrill4/uav-harness-tester, then flash with pio run -t upload (or the Upload button in PlatformIO/VS Code).

---

## 9. Troubleshooting

| Symptom | Possible Cause | Fix |
|---|---|---|
| Device won't power on | GPIO0 pulled low at boot (forces download mode, looks like "won't boot") | Check nothing is shorting GPIO0 low at power-up; confirm BOOT button isn't stuck |
| Device won't power on	| Onboard voltage regulator (5V/3.3V) failure |	Measure regulator output pins directly; if no output, regulator or its input caps may have failed
| Device won't power on	| Short circuit on board (solder bridge, pinched wire) drawing excess current	| Disconnect load/peripherals one at a time; check for hot components; inspect under magnification for bridges
| SD card error on first boot | `SPI.begin()` not called before SD access | Confirmed firmware fix applied (SPI now initialized before SD mount) — update firmware if still seen |
| Display shows garbled or no output | Wrong display driver assumed, or wiring fault | Confirm hardware is the ILI9341 SPI TFT, not an I2C character LCD; check SPI wiring |
| SD card or scan behaves erratically after golden sample capture | GPIO conflict (e.g. SD_CS sharing a pin with a sense-enable line) | Confirmed resolved in current pin map — verify you're on firmware with the de-conflicted `Config.h` |
| Golden Sample Capture always fails / 0 wires detected | Harness not seated, or wrong connector (J1 vs J2) | Reseat harness; confirm correct connector used |
| False SHORT readings | Dirty/oxidized contacts, pinched insulation | Clean contacts; inspect harness for damage; retest |
| RGB LED flickers during scan | Expected — GPIO48 is shared with the onboard RGB LED | No action needed, cosmetic only |
| Display text colors don't match this guide | Firmware color mapping changed since this guide was written | Check `DisplayManager` source against firmware version in the header of this guide |

*Keep this table growing as real-world issues are found during bring-up and use.*

---

## 10. Technical Specifications

| Spec | Value |
|---|---|
| Microcontroller | ESP32-S3-WROOM-1 (N16R8, Octal PSRAM) |
| Display | ILI9341 SPI TFT |
| Matrix size | [64×64 or actual configured size] |
| Connectors | J1 / J2 - type depending on harnesses being tested |
| Umbilical cable | D-Sub connector cable |
| Power | USB-C |
| Dimensions / weight | [ ] |
| Operating temperature | [10–60 °C, cable-limited] |
| Storage | microSD, 8GB |

---

## 11. Appendix

- **A. Full pinout / wiring reference** — [Workflow/wiring-reference.md](Workflow/wiring-reference.md)
- **B. Fault report file format** — [Workflow/fault-report-format.md](Workflow/fault-report-format.md)
- **C. Glossary**
  - *Golden Sample* — a verified-good harness scan used as the reference for pass/fail comparison
  - *OPEN / SHORT / MISMATCH* — as defined above
  - *ACTIVE_WIRE_MASK* — identifies which wires, channels, or signal lines are currently active. Each bit in the mask typically represents one wire: a bit value of 1 means that wire is active, while 0 means it is inactive. This allows multiple active wires to be represented efficiently in a single value

- **E. Support / contact**
  - Repo link: github.com/Hberrill4/uav-harness-tester

---

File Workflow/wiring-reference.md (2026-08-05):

# Wiring reference

All pin assignments live in a single place: `include/Config.h`. Nothing else
in the codebase should hardcode a GPIO number — if you rewire something,
this is the only file you should need to touch.

## Pins assigned

### Mux Select Lines

| Connection | GPIO Pin | Notes |
|---|---|---|
| `PIN_DRIVE_S0` | 13 | |
| `PIN_DRIVE_S1` | 12 | |
| `PIN_DRIVE_S2` | 14 | |
| `PIN_DRIVE_S3` | 15 | |
| `PIN_DRIVE_SIG` | 1 | |
| `PIN_DRIVE_EN[0..3]` | 6, 7, 8, 9 | |
| `PIN_SENSE_S0` | 16 | |
| `PIN_SENSE_S1` | 17 | |
| `PIN_SENSE_S2` | 5 | |
| `PIN_SENSE_S3` | 18 | |
| `PIN_SENSE_SIG` | 48 | Moved off GPIO46 (strapping pin) |
| `PIN_SENSE_EN[0..3]` | 21, 10, 11, 38 | |

### Shared SPI Bus (SD card + TFT, each with its own CS)

| Connection | GPIO Pin | Notes |
|---|---|---|
| `PIN_SPI_SCK` | 19 | |
| `PIN_SPI_MOSI` | 20 | |
| `PIN_SPI_MISO` | 47 | |

### SD Card (SPI)

| Connection | GPIO Pin | Notes |
|---|---|---|
| `PIN_SD_CS` | 39 | |

### TFT Display (2.8" ILI9341, SPI)

| Connection | GPIO Pin | Notes |
|---|---|---|
| `PIN_TFT_CS` | 40 | |
| `PIN_TFT_DC` | 41 | |
| `PIN_TFT_RST` | 42 | |

// STATUS RGB LED (discrete LED, separate from the onboard addressable one)
// ---------------------------------------------------------------------------
static const uint8_t PIN_LED_R = 2;
static const uint8_t PIN_LED_G = 0;    // strapping pin; safe as an OUTPUT
static const uint8_t PIN_LED_B = 3;    // strapping pin; safe as an OUTPUT

// GPIO46 intentionally left unassigned - see notes above.

## Wire numbering convention

Wires are indexed **0-63 internally**. The harness uses **two identical
32-pin connectors** (`J1` and `J2`), so the firmware converts internal
indices to physical locations automatically:

- Wire index `0-31` → connector **J1**, pin `(index % 32) + 1`
- Wire index `32-63` → connector **J2**, pin `(index % 32) + 1`

This mapping lives in `src/WireMap.h` (`wireLabel()`), and both the LCD and
the SD log use it — fault reports show real connector/pin labels like
`J1-13` or `SHORT J1-5<->J2-9`, not abstract wire numbers. If your
connector pin-out doesn't match a simple sequential 1-32 order (e.g. a
circular connector with a non-sequential pin layout), update `wireLabel()`
to do the correct index→pin translation for your specific part.

## Mux addressing

Wire index → mux + channel:

```
muxIndex = wireIndex / 16   // which of the 4 muxes in the bank (0-3)
channel  = wireIndex % 16   // which of the 16 channels on that mux (0-15)
```

`MuxController` handles this internally — you never need to compute it by
hand, but it's worth understanding when debugging with a multimeter.

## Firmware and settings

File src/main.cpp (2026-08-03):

#include <Arduino.h>
#include <time.h>
#include "Config.h"
#include "ButtonManager.h"
#include "MuxController.h"
#include "ContinuityTester.h"
#include "FaultAnalyzer.h"
#include "DisplayManager.h"
#include "StorageManager.h"

ButtonManager    button;
MuxController    mux;
ContinuityTester tester;
DisplayManager   display_;
StorageManager   storage;

UIMode currentMode = UIMode::NORMAL;
bool   resultHeld  = false;   // true while a pass/fail/save/error result is on screen

void setup()
{
    Serial.begin(115200);

Serial.println("1");
button.begin();

Serial.println("2");
mux.begin();

Serial.println("3");
tester.begin(&mux);

Serial.println("4");
display_.begin();

Serial.println("5");

    display_.showSelfTest();

    if (!storage.begin()) {

        display_.showSDWriteError();

        while (true) {
            delay(100);
        }
    }

    TestResult temp;

    if (!storage.loadGoldenSample(temp)) {
        display_.showNoGoldenSample();
    }
    else {
        display_.showIdle(currentMode);
    }
}

void loop() {
    button.update();

    // --- Mode toggle: fires once, exactly when the hold crosses 5s ---
    if (button.longPressEvent()) {
        resultHeld = false; // don't let a stale held result linger across a mode switch
        currentMode = (currentMode == UIMode::NORMAL) ? UIMode::ADMIN : UIMode::NORMAL;
        display_.showIdle(currentMode);
        return;
    }

    // --- Short press: meaning depends on whether a result is currently held ---
    if (button.shortPressEvent()) {

        if (resultHeld) {
            // This press just dismisses the held result and returns to idle.
            resultHeld = false;
            display_.showIdle(currentMode);
            return;
        }

        if (currentMode == UIMode::NORMAL) {

            // Testing is disabled until a golden sample exists - check first
            // so we don't waste a ~0.3s scan when there's nothing to compare against.
            TestResult expected;
            if (!storage.loadGoldenSample(expected)) {
                display_.showNoGoldenSample();
                delay(2500);
                display_.showIdle(currentMode);
                return;
            }

            TestResult actual = tester.runScan();
            FaultReport report = FaultAnalyzer::analyze(actual, expected);

            if (!storage.logResult(report, time(nullptr))) {
                display_.showSDWriteError();
                resultHeld = true; // error stays on screen until next press
                return;
            }

            display_.showResult(currentMode, report);
            resultHeld = true; // pass or fail - both now wait for the next press

        } else { // ADMIN mode: capture current wiring as the new reference

            TestResult golden = tester.runScan();

            if (!storage.saveGoldenSample(golden)) {
                display_.showSDWriteError();
                resultHeld = true; // consistent with the logResult failure above
                return;
            }

            storage.logGoldenSampleEvent(time(nullptr)); // note the change in the test log
            display_.showGoldenSaved();
            resultHeld = true;
        }

        // No auto-return-to-idle here anymore -
        // the screen now waits for the next press to dismiss.
    }
}

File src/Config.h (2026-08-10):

#pragma once
#include <Arduino.h>

// ---------------------------------------------------------------------------
// HARNESS GEOMETRY
// ---------------------------------------------------------------------------
static const uint8_t  NUM_WIRES        = 64;
static const uint8_t  MUXES_PER_BANK   = 4;
static const uint8_t  CHANNELS_PER_MUX = 16;

static const uint8_t  PINS_PER_CONNECTOR = 32;
static const char*    CONNECTOR_A_NAME   = "J1";
static const char*    CONNECTOR_B_NAME   = "J2";

static const uint64_t ACTIVE_WIRE_MASK = 0xFFFFFFFFFFFFFFFFULL;
static const uint8_t MAX_FAULTS_ON_SCREEN = 8;
// ---------------------------------------------------------------------------
// BOARD: Waveshare ESP32-S3-DEV-KIT-N8R8 / NXRX / NxR8 (Octal PSRAM)
// Pin-header compatible with the official ESP32-S3-DevKitC-1.
// ---------------------------------------------------------------------------
// Confirmed restrictions for THIS board:
//   - GPIO22-25 don't exist on the S3 chip.
//   - GPIO26-32 = internal SPI flash bus            -> never use.
//   - GPIO35-37 = internal Octal PSRAM bus (N8R8)    -> never use.
//   - GPIO43/44 = UART0, wired to the onboard CH343 USB-UART bridge
//     (your flashing/Serial path)                   -> avoid for I/O.
//   - GPIO0/3/45/46 = strapping pins (boot mode, JTAG, flash voltage)
//                                                    -> avoid for I/O.
//   - GPIO48 drives this board's onboard addressable RGB LED. Used below
//     for PIN_SENSE_SIG (a pure input) - the onboard LED will flicker
//     during scans as a side effect. Cosmetic only, no functional impact.
// ---------------------------------------------------------------------------

// ---------------------------------------------------------------------------
// BUTTON
// ---------------------------------------------------------------------------
static const uint8_t  PIN_BUTTON        = 4;
static const uint32_t DEBOUNCE_MS       = 30;
static const uint32_t LONG_PRESS_MS     = 5000;

// ---------------------------------------------------------------------------
// MUX SELECT LINES
// ---------------------------------------------------------------------------
static const uint8_t PIN_DRIVE_S0   = 13;
static const uint8_t PIN_DRIVE_S1   = 12;
static const uint8_t PIN_DRIVE_S2   = 14;
static const uint8_t PIN_DRIVE_S3   = 15;
static const uint8_t PIN_DRIVE_SIG  = 1;
static const uint8_t PIN_DRIVE_EN[MUXES_PER_BANK] = {6, 7, 8, 9};

static const uint8_t PIN_SENSE_S0   = 16;
static const uint8_t PIN_SENSE_S1   = 17;
static const uint8_t PIN_SENSE_S2   = 5;
static const uint8_t PIN_SENSE_S3   = 18;
static const uint8_t PIN_SENSE_SIG  = 48;   // moved off GPIO46 (strapping pin)
static const uint8_t PIN_SENSE_EN[MUXES_PER_BANK] = {21, 10, 11, 38};

// ---------------------------------------------------------------------------
// SHARED SPI BUS (SD card + TFT, each with its own CS)
// ---------------------------------------------------------------------------
static const uint8_t PIN_SPI_SCK   = 19;   // moved off GPIO33 (Octal PSRAM bus)
static const uint8_t PIN_SPI_MOSI  = 20;   // moved off GPIO34 (Octal PSRAM bus)
static const uint8_t PIN_SPI_MISO  = 47;

// ---------------------------------------------------------------------------
// SD CARD (SPI)
// ---------------------------------------------------------------------------
static const uint8_t PIN_SD_CS = 39;

// ---------------------------------------------------------------------------
// TFT DISPLAY (2.8" ILI9341, SPI)
// ---------------------------------------------------------------------------
static const uint8_t PIN_TFT_CS  = 40;
static const uint8_t PIN_TFT_DC  = 41;
static const uint8_t PIN_TFT_RST = 42;

// ---------------------------------------------------------------------------
// STATUS RGB LED (discrete LED, separate from the onboard addressable one)
// ---------------------------------------------------------------------------
static const uint8_t PIN_LED_R = 2;
static const uint8_t PIN_LED_G = 0;    // strapping pin; safe as an OUTPUT
static const uint8_t PIN_LED_B = 3;    // strapping pin; safe as an OUTPUT

// GPIO46 intentionally left unassigned - see notes above.

// ---------------------------------------------------------------------------
// FILES
// ---------------------------------------------------------------------------
static const char* LOG_FILE_PATH    = "/test_log.csv";
static const char* GOLDEN_FILE_PATH = "/golden_sample.bin";

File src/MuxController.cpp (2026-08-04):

#include "MuxController.h"
#include "Config.h"



void MuxController::begin() {
    pinMode(PIN_DRIVE_S0, OUTPUT);
    pinMode(PIN_DRIVE_S1, OUTPUT);
    pinMode(PIN_DRIVE_S2, OUTPUT);
    pinMode(PIN_DRIVE_S3, OUTPUT);
    pinMode(PIN_DRIVE_SIG, OUTPUT);

    pinMode(PIN_SENSE_S0, OUTPUT);
    pinMode(PIN_SENSE_S1, OUTPUT);
    pinMode(PIN_SENSE_S2, OUTPUT);
    pinMode(PIN_SENSE_S3, OUTPUT);
    pinMode(PIN_SENSE_SIG, INPUT_PULLDOWN); // reads HIGH only if continuity exists

    for (uint8_t i = 0; i < MUXES_PER_BANK; i++) {
        pinMode(PIN_DRIVE_EN[i], OUTPUT);
        digitalWrite(PIN_DRIVE_EN[i], HIGH); // HIGH = disabled
        pinMode(PIN_SENSE_EN[i], OUTPUT);
        digitalWrite(PIN_SENSE_EN[i], HIGH);
    }

    digitalWrite(PIN_DRIVE_SIG, LOW);
}

void MuxController::setSelectLines(uint8_t s0, uint8_t s1, uint8_t s2, uint8_t s3, uint8_t channel) {
    digitalWrite(s0, (channel >> 0) & 0x01);
    digitalWrite(s1, (channel >> 1) & 0x01);
    digitalWrite(s2, (channel >> 2) & 0x01);
    digitalWrite(s3, (channel >> 3) & 0x01);
}

void MuxController::selectDrive(uint8_t wireIndex) {
    uint8_t muxIndex = wireIndex / CHANNELS_PER_MUX;
    uint8_t channel  = wireIndex % CHANNELS_PER_MUX;

    setSelectLines(PIN_DRIVE_S0, PIN_DRIVE_S1, PIN_DRIVE_S2, PIN_DRIVE_S3, channel);

    for (uint8_t i = 0; i < MUXES_PER_BANK; i++) {
        digitalWrite(PIN_DRIVE_EN[i], (i == muxIndex) ? LOW : HIGH);
    }
}

void MuxController::selectSense(uint8_t wireIndex) {
    uint8_t muxIndex = wireIndex / CHANNELS_PER_MUX;
    uint8_t channel  = wireIndex % CHANNELS_PER_MUX;

    setSelectLines(PIN_SENSE_S0, PIN_SENSE_S1, PIN_SENSE_S2, PIN_SENSE_S3, channel);

    for (uint8_t i = 0; i < MUXES_PER_BANK; i++) {
        digitalWrite(PIN_SENSE_EN[i], (i == muxIndex) ? LOW : HIGH);
    }
}

void MuxController::disableAllDrive() {
    for (uint8_t i = 0; i < MUXES_PER_BANK; i++) digitalWrite(PIN_DRIVE_EN[i], HIGH);
}

void MuxController::disableAllSense() {
    for (uint8_t i = 0; i < MUXES_PER_BANK; i++) digitalWrite(PIN_SENSE_EN[i], HIGH);
}

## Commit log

2026-07-13 Add connector+pin fault labeling for two-connector harness
    Replace abstract wire index numbers in fault reports with real
    connector+pin locations, matching the harness's two 32-pin connector
    layout (J1, J2).
    - Add WireMap.h: converts internal wire index (0-63) to a physical
    label (e.g. index 12 -> "J1-13", index 45 -> "J2-14")
    - Update DisplayManager to show fault locations as connector/pin
    labels on the LCD (e.g. "SHORT J1-5<->J2-9")
    - Update StorageManager to log the same labels to the SD card CSV
    instead of raw wire numbers
    - Update docs/wiring-reference.md and docs/fault-report-format.md
    to reflect the confirmed 32+32 connector split
    Assumes sequential 1-32 pin numbering on bot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
    [Config.h, DisplayManager.cpp]
2026-07-13 added powerpoint and debugged
2026-07-14 added excel
    [BOM for project.xlsx, Gant Chart.xlsx]
2026-07-14 Correct file paths for Gantt Chart and BOM
    Updated file paths for project documentation.
2026-07-14 Fix file names in Project Files section
    Updated file names for Bill of Materials and Gantt Chart.
2026-07-14 Fix links for Bill of Materials and Gantt Chart
2026-07-14 Enhance design architecture documentation with details
    Expanded on the initial design ideas and input method considerations, highlighting potential issues with complexity and usability. Added section on harness and cable considerations for improved connection stability.
2026-07-14 allow less than 64 wires
2026-07-14 Enhance README with possible errors and resolutions
    Added section on possible errors and resolutions related to wire loom testing.
2026-07-14 Update README with error handling and resolution details
    Clarified error handling for wire loom validation and added notes on golden sample submission.
2026-07-14 Fix typos and improve clarity in README
    Corrected typos and clarified error messages regarding wire loom validation in the README.
2026-07-16 Correct resolution formatting in README
    Fixed formatting issue in the resolution section for wire loom errors.
2026-07-16 Update README with error handling resolutions
    Clarified error handling for wire loom testing and added resolution details.
2026-07-17 updated version
    [BOM for project.xlsx]
2026-07-17 web page view
    [BOM for project.xlsx]
2026-07-17 try again
    [BOM for project.xlsx]
2026-07-17 Update BOM file with cost formatting changes
    [BOM for project.csv]
2026-07-17 Update Dsub connectors description in BOM
    [BOM for project.csv]
2026-07-17 Update BOM with new D-Sub cable description
    [BOM for project.csv]
2026-07-17 Update Dsub coupler description in BOM
    [BOM for project.csv]
2026-07-17 Modify BOM CSV header and product link column
    Updated the header and corrected the product link column name in the BOM.
    [BOM for project.csv]
2026-07-27 display changes for less than 64 wires
    no longer assumes any positions and requires a golden harness to be submitted
    [DisplayManager.cpp, main.cpp]
2026-07-29 SD write failiures and setip failiure
    [DisplayManager.cpp, main.cpp]
2026-07-29 new pin outs and changes
2026-07-30 prototype guide
2026-07-30 updated pcb process
2026-07-31 Revise assembly instructions in README.md
    Updated README with confirmed steps and clarifications for each phase of the assembly process.
2026-07-31 Update README with final hardware and connector info
    Added final hardware specifications and connector details.
2026-07-31 Add requirements section to design architecture README
    Added requirements for the design architecture including specifications for the device and its functionalities.
2026-07-31 Revert "rename"
    This reverts commit 1958be347c3be804021692f93082ab67a682dac7.
    [BOM for project.csv, Gant Chart.xlsx]
2026-07-31 Revert "cleaning up"
    This reverts commit e5c6e54bf3aec84b27369471dc692c52aa3984d3.
    [Config.h]
2026-08-03 Fix link to Bill of Materials in README
2026-08-03 press button to return
2026-08-03 Remove RGB LED pin definitions from Config.h
    Removed RGB LED pin definitions and related comments.
2026-08-03 Revert "Remove RGB LED pin definitions from Config.h"
    This reverts commit f6b4a127dd926aba45dc4d86f9c58a9b2fc54642.
    [Config.h]
2026-08-05 Revise hardware section titles and BOM mention
    Updated section titles and clarified BOM reference in README.
2026-08-05 Add user guide for UAV Wire Harness Continuity Tester
    Added a comprehensive user guide for the UAV Wire Harness Continuity Tester, including sections on introduction, safety information, product overview, operating instructions, troubleshooting, and tec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
2026-08-05 Revise wiring-reference.md for better formatting
    Updated formatting for wiring reference documentation to improve clarity and consistency.
2026-08-06 Create Specific wire reference
2026-08-06 Rename Specific wire reference to Specific-wire-reference.md
2026-08-06 Update Specific-wire-reference.md with S1 to S6
    Added sections for S1 to S6 with connection types and colors.
2026-08-06 Remove empty wire reference for PPM connection
2026-08-06 Update S1 section in Specific-wire-reference.md
2026-08-06 Update wire reference colors for receiver connections
2026-08-06 Revise wire reference details in documentation
    Updated wire reference table with specific connections and colors.
2026-08-06 Add icons to connection types in wire reference
2026-08-18 Remove phases 6 to 9 from README
    Removed phases 6 to 9 from the README, including details on wiring, testing, and mechanical integration.
2026-08-18 Update BOM link for test pod in README.md
2026-08-18 Revise README with circuit protection and updates
    Updated PCB design documentation with new circuit protection details and revised specifications.
2026-08-18 Update README with PCB and enclosure details
    Added information about custom PCB and enclosure for the project.
2026-08-18 Update README to include PCB and enclosure details
    Added sections for custom PCB and enclosure.
2026-08-18 Rename WireHarnessTesterV9.kicad_sch to Active PCB schematic
2026-08-19 Fix voltage notation in README.md
    Corrected the voltage notation from '3.3 V' to '3.3V' for consistency.
2026-09-08 Update README with additional PCB resources
    Added links to PCB schematic and PCB image in README.
2026-09-08 Fix formatting in README.md for enclosure links
2026-09-09 Update README to clarify PCB and enclosure links
    Removed duplicate PCB image reference and added enclosure links.
